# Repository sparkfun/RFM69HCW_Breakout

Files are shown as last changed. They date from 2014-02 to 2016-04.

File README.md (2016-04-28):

RFM69HCW Breakout Board
=================
The RFM69HCW is an inexpensive and versatile radio module that operates in the unlicensed ISM (Industry, Science, and Medicine) radio band. It's perfect for building inexpensive short-range wireless networks of sensors and actuators for home automation, citizen science, and more.

(https://cdn.sparkfun.com/assets/parts/9/6/6/5/12823-00.jpg)

Specs
----------------

* Transmit power: -18dBm (0.016mW) to +20dBm (100mW) in 1dBm steps
* Receive sensitivity: down to -120dBm at 1.2kbps
* Modulation types: FSK GFSK MSK GMSK OOK
* Bit rates (FSK): 1.2kbps to 300kbps
* Voltage range: 1.8V to 3.6V
* Current consumption: 0.1uA sleep, 1.25mA standby, 16mA receive, 
* 130mA transmit (max)
* Encryption: AES 128-bit (optional)
* Packet buffer (FIFO): 66 bytes
* Dimensions: 0.8" x 1.1"

Product Versions
----------------

The RFM69HCW modules transmit in the [ISM band](http://en.wikipedia.org/wiki/ISM_band), which is reserved for short-range, low-power communications. SparkFun sells the RFM69HCW Breakout Board in two frequencies:

* [**RFM69HCW Breakout 915MHz (WRL-12775)**](https://www.sparkfun.com/products/12775)
* [**RFM69HCW Breakout 433MHz (WRL-12823)**](https://www.sparkfun.com/products/12823)

Broadly speaking, the 915MHz version is legal in [ITU region](http://en.wikipedia.org/wiki/ITU_region) 2 (North and South America, Australia, Greenland, Pacific Islands, Israel), and the 433MHz version is legal in [ITU region](http://en.wikipedia.org/wiki/ITU_region) 1 (Europe, Africa, Middle East, Russia). Other areas have mixed allocations; hobbyist use is not likely to be an issue, but if you're going to be deploying a lot of these or using them in a commercial product, check your local regulations.

Documentation
-------------------

* [**Hookup Guide**](https://learn.sparkfun.com/tutorials/rfm69hcw-hookup-guide)
* [**RFM69HCW Breakout Board Schematic**](https://github.com/sparkfun/RFM69HCW_Breakout/blob/master/documentation/RFM69HCW_BOB.pdf)
* [**RFM69HCW datasheet**](https://github.com/sparkfun/RFM69HCW_Breakout/blob/master/documentation/RFM69HCW-V1.1.pdf)
* [**HopeRF RFM69HCW product page (external link)**](http://www.hoperf.com/rf/fsk_module/RFM69HCW.htm)

Repository Contents
-------------------
* [**/Libraries/Arduino**](https://github.com/sparkfun/RFM69HCW_Breakout/tree/master/Libraries/Arduino) - Contains the [RFM69 library](https://github.com/LowPowerLab/RFM69) written by Felix Rusu of [LowPowerLab.com](lowpowerlab.com). See [https://github.com/LowPowerLab/RFM69](https://github.com/LowPowerLab/RFM69) for the most up-to-date version.

* [**/Libraries/Arduino/RFM69/examples**](https://github.com/sparkfun/RFM69HCW_Breakout/tree/master/Libraries/Arduino/RFM69/examples) - Example Arduino sketch showing how to use the SparkFun RFM69HCW breakout board. See the hook-up guide at [https://learn.sparkfun.com/tutorials/rfm69hcw-hookup-guide](https://learn.sparkfun.com/tutorials/rfm69hcw-hookup-guide) for wiring and usage details.

* [**/hardware**](https://github.com/sparkfun/RFM69HCW_Breakout/tree/master/hardware) - Eagle design files (.brd, .sch)

* [**/documentation**](https://github.com/sparkfun/RFM69HCW_Breakout/tree/master/documentation) - Datasheets, schematic, etc.

Attribution
-----------
We gratefully acknowledge Felix Rusu of [LowPowerLab.com](lowpowerlab.com) for his terrific [RFM69 library](https://github.com/LowPowerLab/RFM69), which runs on his very cool [Moteino](http://lowpowerlab.com/moteino/) hardware. A version of his library is included here for the convenience of SparkFun customers. Please see his [GitHub repository](https://github.com/LowPowerLab/RFM69) for the latest version.

License Information
-------------------
The hardware design is released under the [Creative Commons Attribution-ShareAlike 4.0 International](http://creativecommons.org/licenses/by-sa/4.0/) license.

Felix Rusu's RFM69 library is released under the [Creative Commons Attribution-ShareAlike 3.0](http://creativecommons.org/licenses/by-sa/3.0/) license. 

SparkFun's example code is based on Felix Rusu's work, and is thus released under the same [Creative Commons Attribution-ShareAlike 3.0](http://creativecommons.org/licenses/by-sa/3.0/) license.

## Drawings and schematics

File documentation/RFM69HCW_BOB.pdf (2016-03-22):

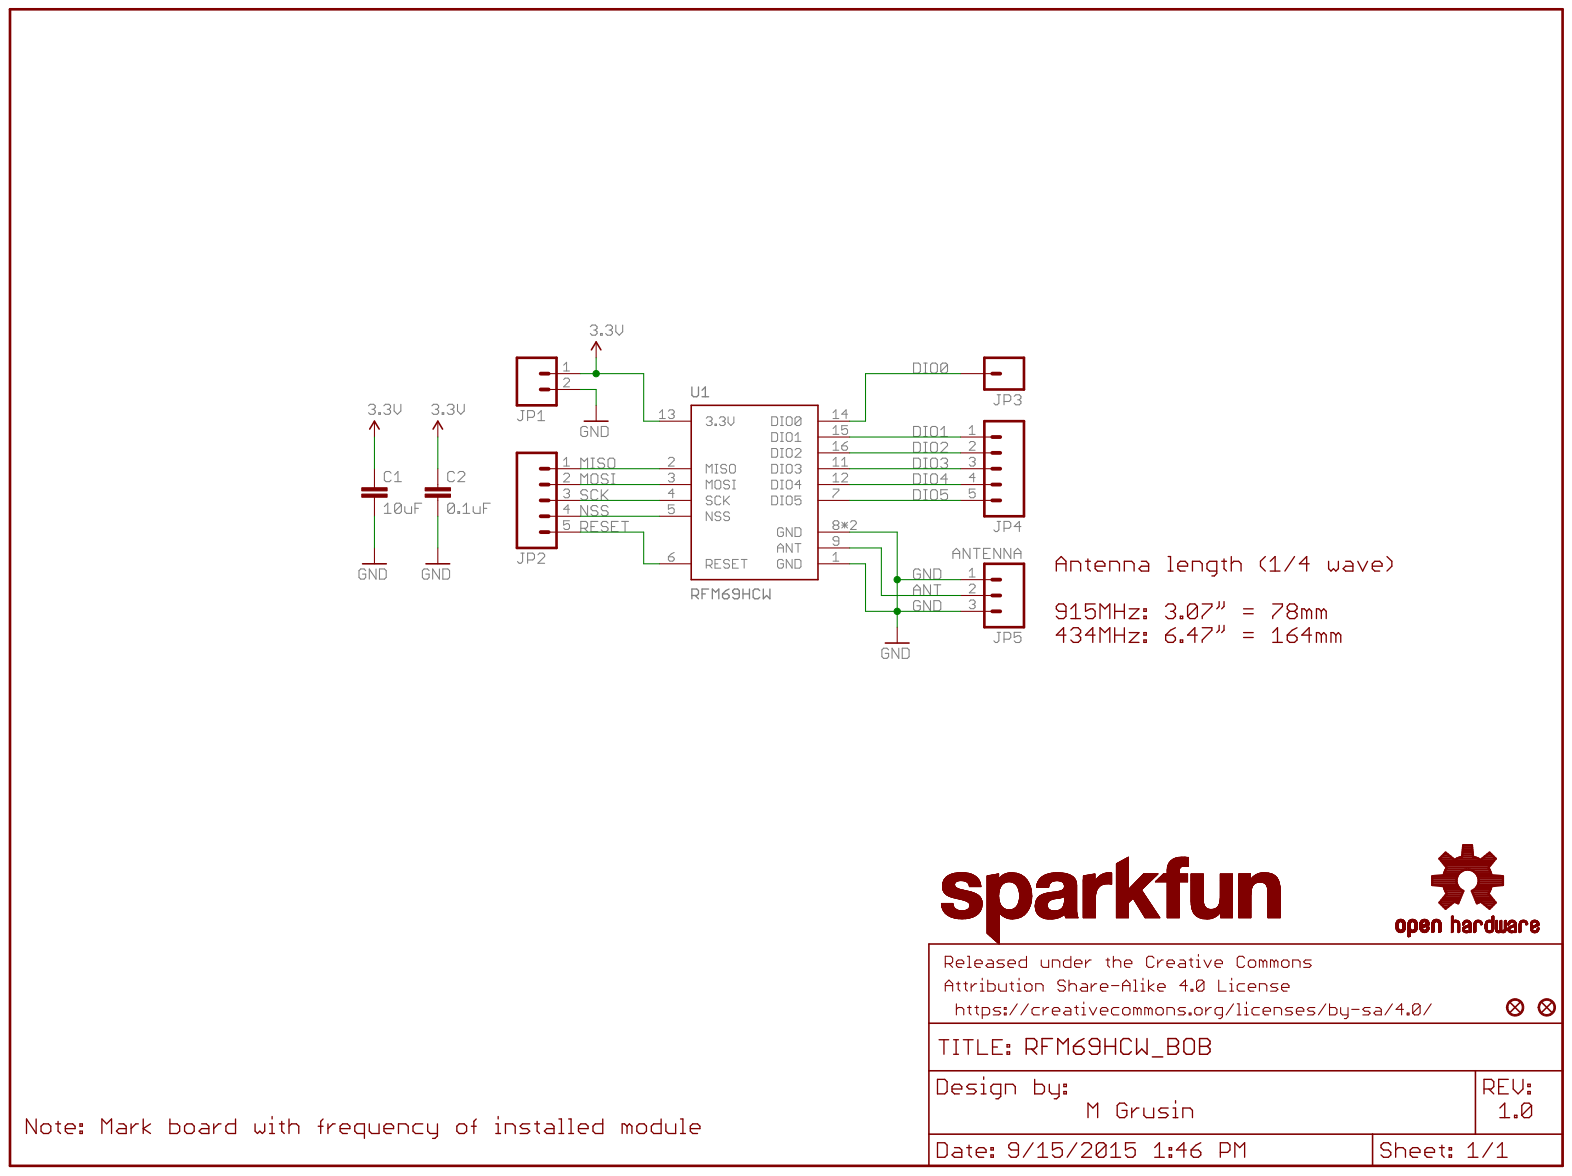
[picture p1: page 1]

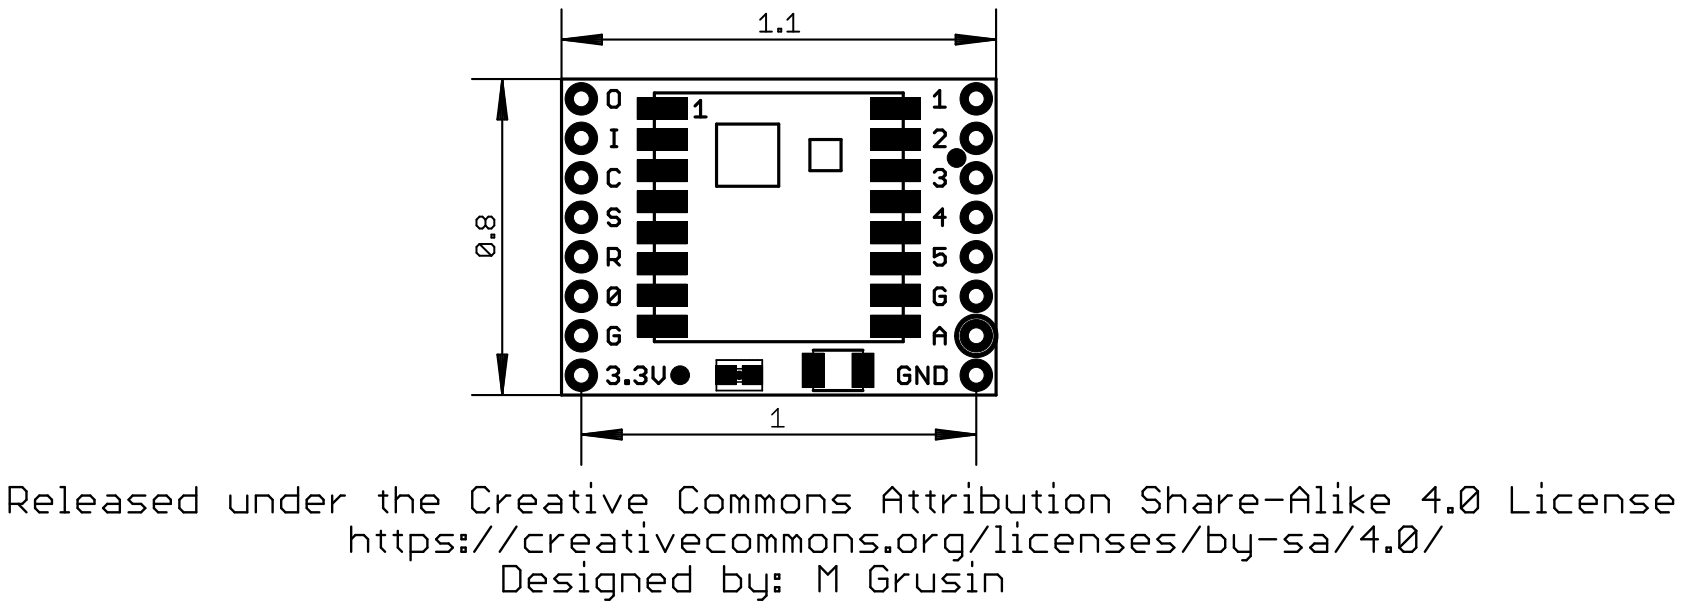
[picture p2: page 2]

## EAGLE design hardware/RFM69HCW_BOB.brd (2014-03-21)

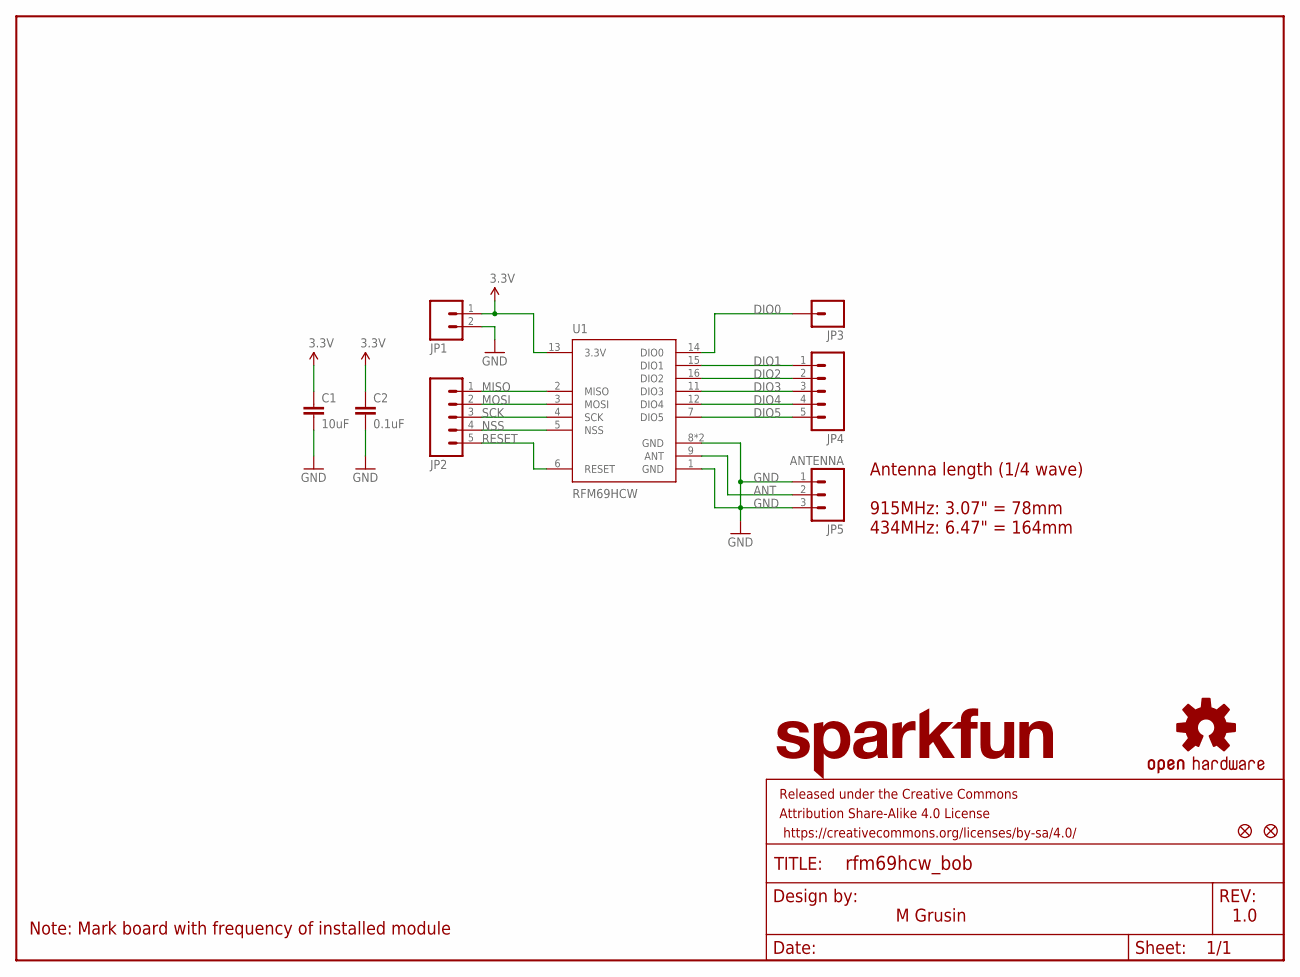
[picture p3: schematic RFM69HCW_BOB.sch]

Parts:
C1: 10uF; 1210
C2: 0.1uF; 0603-CAP
FID1, FID2: FIDUCIAL1X2; FIDUCIAL-1X2
FRAME1: FRAME-LETTER; CREATIVE_COMMONS
JP1: M021X02_NO_SILK; 1X02_NO_SILK
JP2, JP4: M05_ROUNDONLY_NOSILK; 1X05_ROUNDONLY_NOSILK
JP3: M01SMDNS; 1X01NS
JP5: ANTENNA; 1X03_ROUND_ONLY_NO_SILK
LOGO1: SFE_LOGO_NAME.1_INCH; SFE_LOGO_NAME_.1
LOGO2: OSHW-LOGOS; OSHW-LOGO-S
U1: RFM69HCW; RFM69HCW-XXXS2

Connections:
3.3V: C1.1, C2.1, JP1.1, U1.13 (3.3V)
ANT: JP5.2, U1.9 (ANT)
DIO0: JP3.1, U1.14 (DIO0)
DIO1: JP4.1, U1.15 (DIO1)
DIO2: JP4.2, U1.16 (DIO2)
DIO3: JP4.3, U1.11 (DIO3)
DIO4: JP4.4, U1.12 (DIO4)
DIO5: JP4.5, U1.7 (DIO5)
GND: C1.2, C2.2, JP1.2, JP5.1, JP5.3, U1.1 (GND), U1.8 (GND), U1.10 (GND)
MISO: JP2.1, U1.2 (MISO)
MOSI: JP2.2, U1.3 (MOSI)
NSS: JP2.4, U1.5 (NSS)
RESET: JP2.5, U1.6 (RESET)
SCK: JP2.3, U1.4 (SCK)

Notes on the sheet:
M Grusin
1.0
Note: Mark board with frequency of installed module
Antenna length (1/4 wave) 915MHz: 3.07" = 78mm 434MHz: 6.47" = 164mm

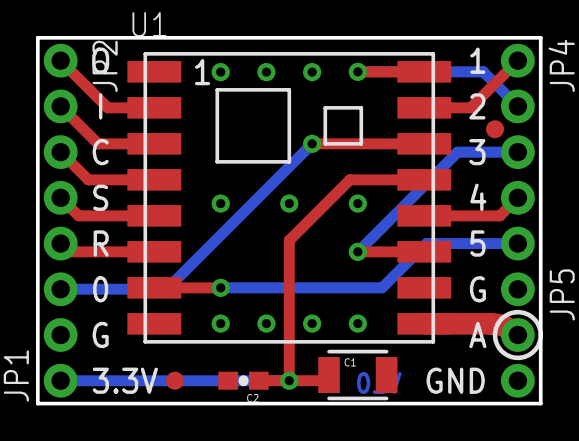
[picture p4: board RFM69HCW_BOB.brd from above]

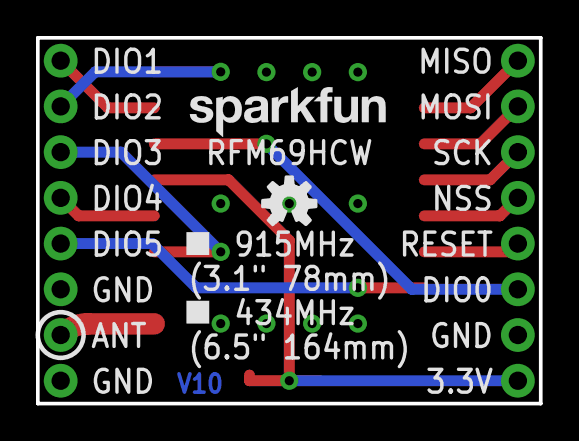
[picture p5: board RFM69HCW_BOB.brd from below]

Board: 2 copper layers, 27.9 x 20.3 mm, 13 parts (2 on the bottom side), 14 nets.

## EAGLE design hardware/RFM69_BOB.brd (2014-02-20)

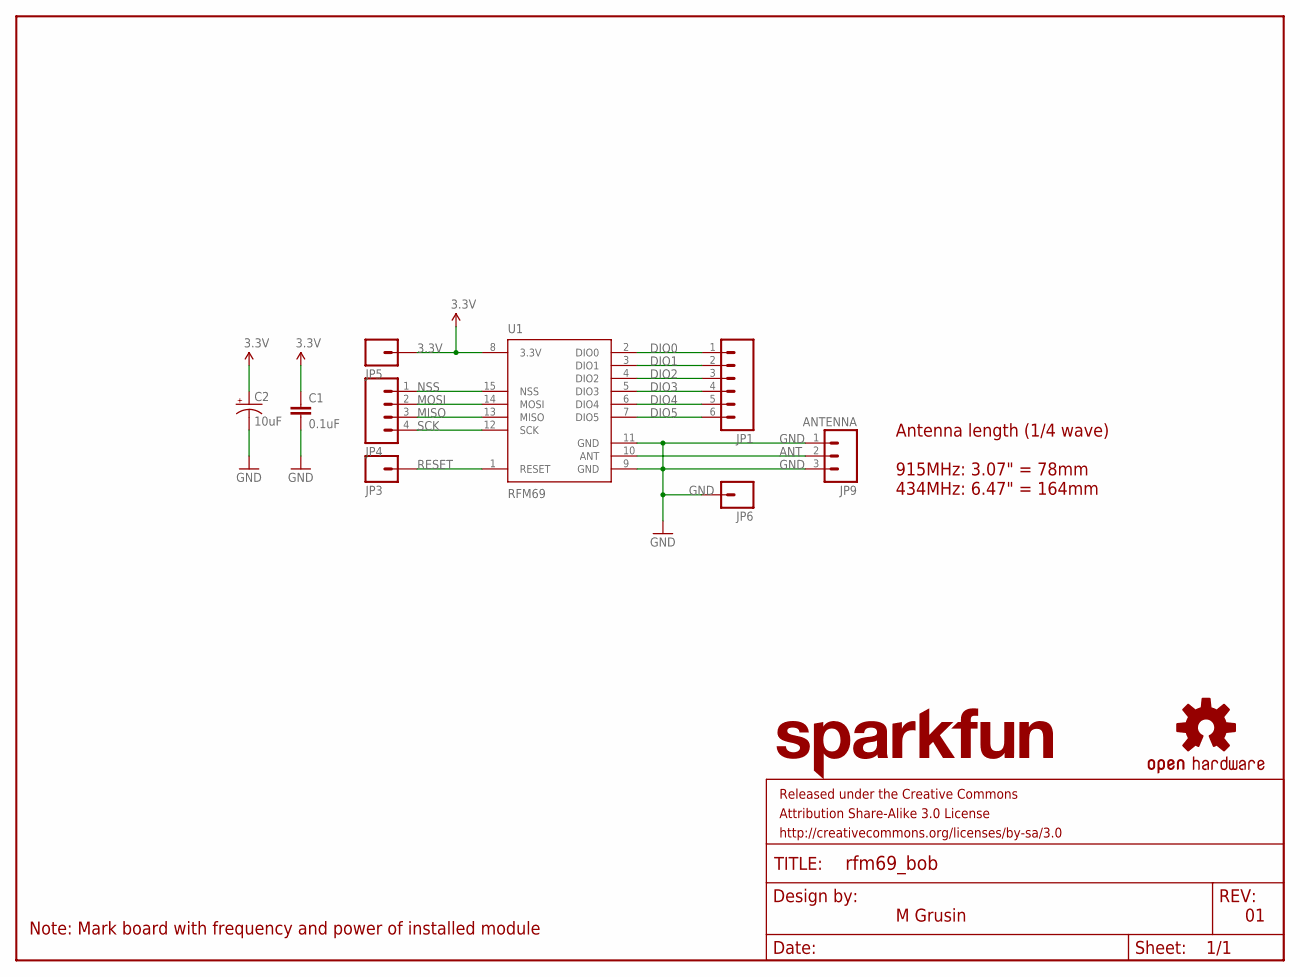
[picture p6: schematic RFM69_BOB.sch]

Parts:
C1: 0.1uF; 0603-CAP
C2: 10uF; EIA3216
FRAME1: FRAME-LETTER; CREATIVE_COMMONS
JP1: M06_NOSILK_ROUND; 1X06_NO_SILK_ROUND
JP3, JP5, JP6: M01SMDNS; 1X01NS
JP4: M041X04_NO_SILK_ROUND; 1X04_NO_SILK_ROUND
JP9: ANTENNA; 1X03_ROUND_ONLY_NO_SILK
LOGO1: SFE_LOGO_NAME.1_INCH; SFE_LOGO_NAME_.1
LOGO2: OSHW-LOGOS; OSHW-LOGO-S
U1: RFM69

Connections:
3.3V: C1.1, C2.A (+), JP5.1, U1.8 (3.3V)
ANT: JP9.2, U1.10 (ANT)
DIO0: JP1.1, U1.2 (DIO0)
DIO1: JP1.2, U1.3 (DIO1)
DIO2: JP1.3, U1.4 (DIO2)
DIO3: JP1.4, U1.5 (DIO3)
DIO4: JP1.5, U1.6 (DIO4)
DIO5: JP1.6, U1.7 (DIO5)
GND: C1.2, C2.C (-), JP6.1, JP9.1, JP9.3, U1.9 (GND), U1.11 (GND)
MISO: JP4.3, U1.13 (MISO)
MOSI: JP4.2, U1.14 (MOSI)
NSS: JP4.1, U1.15 (NSS)
RESET: JP3.1, U1.1 (RESET)
SCK: JP4.4, U1.12 (SCK)

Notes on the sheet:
M Grusin
Note: Mark board with frequency and power of installed module
Antenna length (1/4 wave) 915MHz: 3.07" = 78mm 434MHz: 6.47" = 164mm

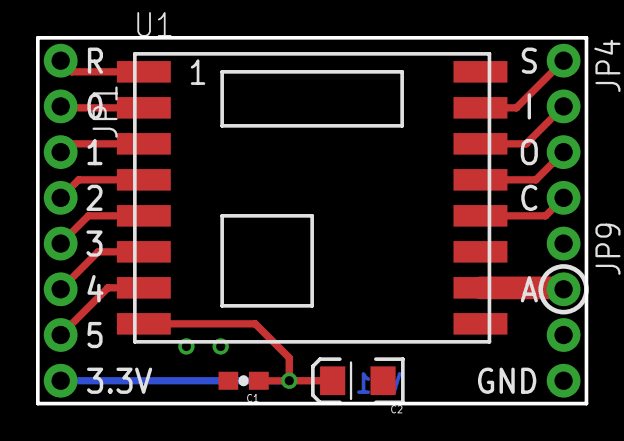
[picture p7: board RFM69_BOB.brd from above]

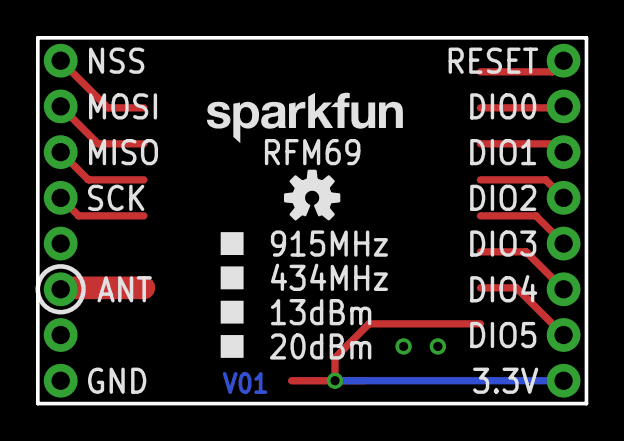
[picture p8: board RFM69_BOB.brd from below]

Board: 2 copper layers, 30.5 x 20.3 mm, 12 parts (2 on the bottom side), 14 nets.

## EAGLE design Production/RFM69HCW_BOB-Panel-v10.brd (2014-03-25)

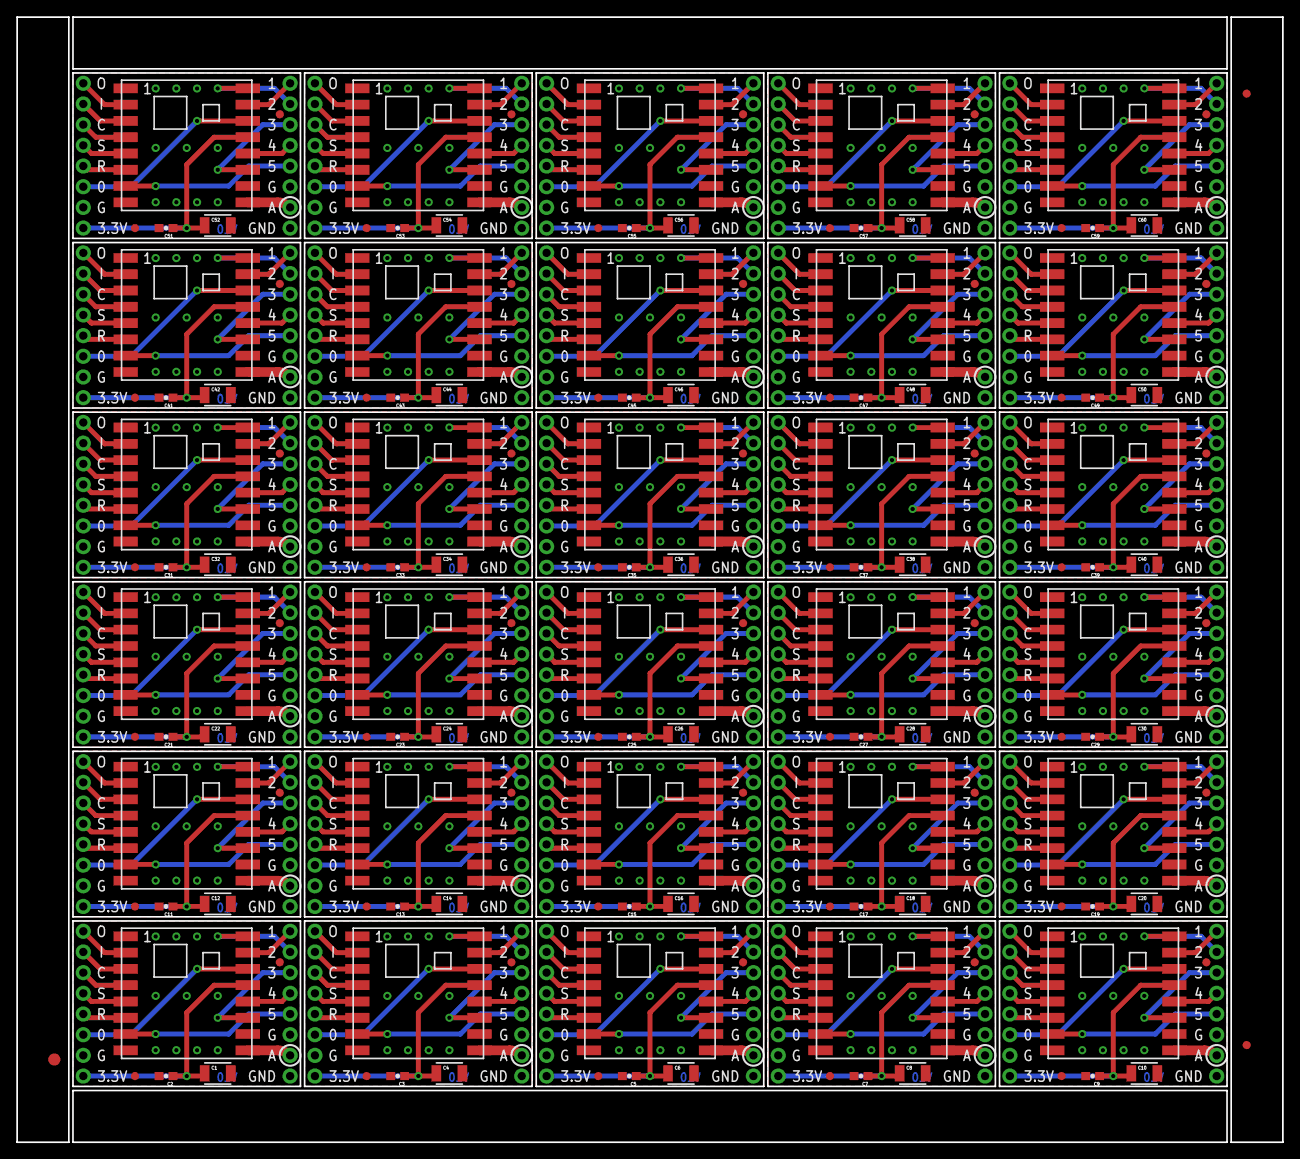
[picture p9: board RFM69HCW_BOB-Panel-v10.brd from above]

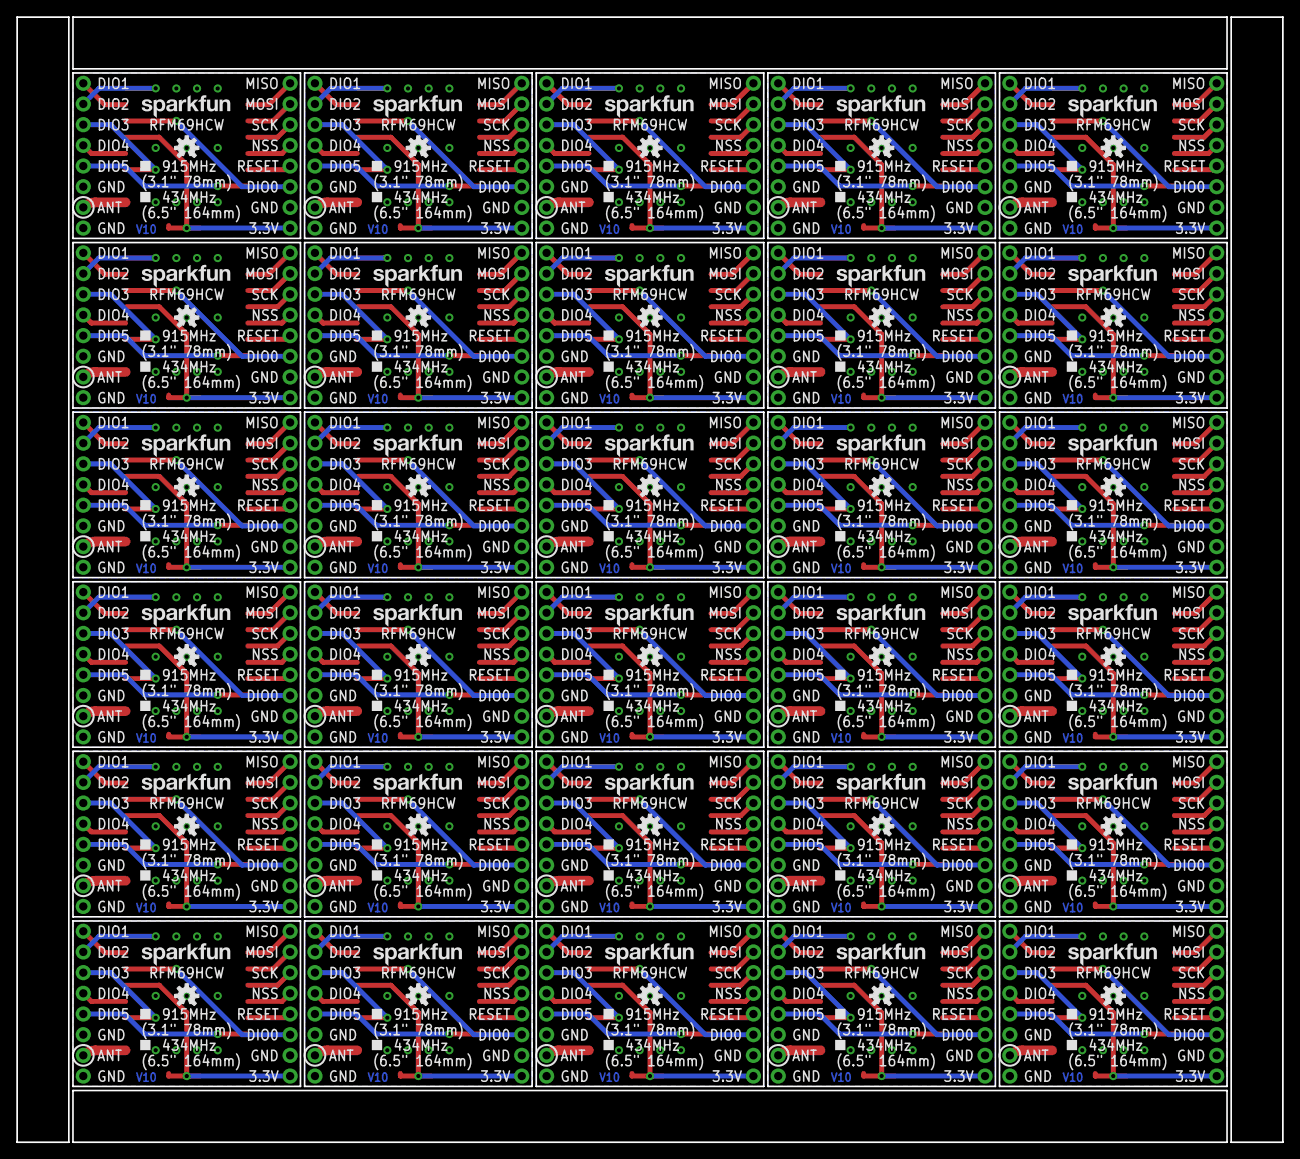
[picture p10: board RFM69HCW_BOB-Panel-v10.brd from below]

Board: 2 copper layers, 155.4 x 138.2 mm, 363 parts (60 on the bottom side), 420 nets.

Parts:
C1, C4, C6, C8, C10, C12, C14, C16, C18, C20, C22, C24, C26, C28, C30, C32, C34, C36, C38, C40, C42, C44, C46, C48, C50, C52, C54, C56, C58, C60: 10uF; 1210
C2, C3, C5, C7, C9, C11, C13, C15, C17, C19, C21, C23, C25, C27, C29, C31, C33, C35, C37, C39, C41, C43, C45, C47, C49, C51, C53, C55, C57, C59: 0.1uF; 0603-CAP
E$1: FIDUCIAL-1.5X3
E$4, E$6: FIDUCIAL-1X2
FID1, FID2, FID3, FID4, FID5, FID6, FID7, FID8, FID9, FID10, FID11, FID12, FID13, FID14, FID15, FID16, FID17, FID18, FID19, FID20, FID21, FID22, FID23, FID24, FID25, FID26, FID27, FID28, FID29, FID30, FID31, FID32, FID33, FID34, FID35, FID36, FID37, FID38, FID39, FID40, FID41, FID42, FID43, FID44, FID45, FID46, FID47, FID48, FID49, FID50, FID51, FID52, FID53, FID54, FID55, FID56, FID57, FID58, FID59, FID60: FIDUCIAL1X2; FIDUCIAL-1X2
JP1, JP7, JP12, JP17, JP22, JP27, JP32, JP37, JP42, JP47, JP52, JP57, JP62, JP67, JP72, JP77, JP82, JP87, JP92, JP97, JP102, JP107, JP112, JP117, JP122, JP127, JP132, JP137, JP142, JP147: 1X02_NO_SILK
JP2, JP4, JP8, JP10, JP13, JP15, JP18, JP20, JP23, JP25, JP28, JP30, JP33, JP35, JP38, JP40, JP43, JP45, JP48, JP50, JP53, JP55, JP58, JP60, JP63, JP65, JP68, JP70, JP73, JP75, JP78, JP80, JP83, JP85, JP88, JP90, JP93, JP95, JP98, JP100, JP103, JP105, JP108, JP110, JP113, JP115, JP118, JP120, JP123, JP125, JP128, JP130, JP133, JP135, JP138, JP140, JP143, JP145, JP148, JP150: 1X05_ROUNDONLY_NOSILK
JP3, JP9, JP14, JP19, JP24, JP29, JP34, JP39, JP44, JP49, JP54, JP59, JP64, JP69, JP74, JP79, JP84, JP89, JP94, JP99, JP104, JP109, JP114, JP119, JP124, JP129, JP134, JP139, JP144, JP149: 1X01NS
JP5, JP6, JP11, JP16, JP21, JP26, JP31, JP36, JP41, JP46, JP51, JP56, JP61, JP66, JP71, JP76, JP81, JP86, JP91, JP96, JP101, JP106, JP111, JP116, JP121, JP126, JP131, JP136, JP141, JP146: ANTENNA; 1X03_ROUND_ONLY_NO_SILK
LOGO1, LOGO3, LOGO5, LOGO7, LOGO9, LOGO11, LOGO13, LOGO15, LOGO17, LOGO19, LOGO21, LOGO23, LOGO25, LOGO27, LOGO29, LOGO31, LOGO33, LOGO35, LOGO37, LOGO39, LOGO41, LOGO43, LOGO45, LOGO47, LOGO49, LOGO51, LOGO53, LOGO55, LOGO57, LOGO59: SFE_LOGO_NAME.1_INCH; SFE_LOGO_NAME_.1
LOGO2, LOGO4, LOGO6, LOGO8, LOGO10, LOGO12, LOGO14, LOGO16, LOGO18, LOGO20, LOGO22, LOGO24, LOGO26, LOGO28, LOGO30, LOGO32, LOGO34, LOGO36, LOGO38, LOGO40, LOGO42, LOGO44, LOGO46, LOGO48, LOGO50, LOGO52, LOGO54, LOGO56, LOGO58, LOGO60: OSHW-LOGOS; OSHW-LOGO-S
U1, U2, U3, U4, U5, U6, U7, U8, U9, U10, U11, U12, U13, U14, U15, U16, U17, U18, U19, U20, U21, U22, U23, U24, U25, U26, U27, U28, U29, U30: RFM69HCW; RFM69HCW-XXXS2

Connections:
3.3V: C1.1, C2.1, JP1.1, U1.13
3.3V1: C3.1, C4.1, JP7.1, U2.13
3.3V2: C5.1, C6.1, JP12.1, U3.13
3.3V3: C7.1, C8.1, JP17.1, U4.13
3.3V4: C9.1, C10.1, JP22.1, U5.13
3.3V5: C11.1, C12.1, JP27.1, U6.13
3.3V6: C13.1, C14.1, JP32.1, U7.13
3.3V7: C15.1, C16.1, JP37.1, U8.13
3.3V8: C17.1, C18.1, JP42.1, U9.13
3.3V9: C19.1, C20.1, JP47.1, U10.13
3.3V10: C21.1, C22.1, JP52.1, U11.13
3.3V11: C23.1, C24.1, JP57.1, U12.13
3.3V12: C25.1, C26.1, JP62.1, U13.13
3.3V13: C27.1, C28.1, JP67.1, U14.13
3.3V14: C29.1, C30.1, JP72.1, U15.13
3.3V15: C31.1, C32.1, JP77.1, U16.13
3.3V16: C33.1, C34.1, JP82.1, U17.13
3.3V17: C35.1, C36.1, JP87.1, U18.13
3.3V18: C37.1, C38.1, JP92.1, U19.13
3.3V19: C39.1, C40.1, JP97.1, U20.13
3.3V20: C41.1, C42.1, JP102.1, U21.13
3.3V21: C43.1, C44.1, JP107.1, U22.13
3.3V22: C45.1, C46.1, JP112.1, U23.13
3.3V23: C47.1, C48.1, JP117.1, U24.13
3.3V24: C49.1, C50.1, JP122.1, U25.13
3.3V25: C51.1, C52.1, JP127.1, U26.13
3.3V26: C53.1, C54.1, JP132.1, U27.13
3.3V27: C55.1, C56.1, JP137.1, U28.13
3.3V28: C57.1, C58.1, JP142.1, U29.13
3.3V29: C59.1, C60.1, JP147.1, U30.13
ANT: JP5.2, U1.9
ANT1: JP6.2, U2.9
ANT2: JP11.2, U3.9
ANT3: JP16.2, U4.9
ANT4: JP21.2, U5.9
ANT5: JP26.2, U6.9
ANT6: JP31.2, U7.9
ANT7: JP36.2, U8.9
ANT8: JP41.2, U9.9
ANT9: JP46.2, U10.9
ANT10: JP51.2, U11.9
ANT11: JP56.2, U12.9
ANT12: JP61.2, U13.9
ANT13: JP66.2, U14.9
ANT14: JP71.2, U15.9
ANT15: JP76.2, U16.9
ANT16: JP81.2, U17.9
ANT17: JP86.2, U18.9
ANT18: JP91.2, U19.9
ANT19: JP96.2, U20.9
ANT20: JP101.2, U21.9
ANT21: JP106.2, U22.9
ANT22: JP111.2, U23.9
ANT23: JP116.2, U24.9
ANT24: JP121.2, U25.9
ANT25: JP126.2, U26.9
ANT26: JP131.2, U27.9
ANT27: JP136.2, U28.9
ANT28: JP141.2, U29.9
ANT29: JP146.2, U30.9
DIO0: JP3.1, U1.14
DIO1: JP4.1, U1.15
DIO2: JP4.2, U1.16
DIO3: JP4.3, U1.11
DIO4: JP4.4, U1.12
DIO5: JP4.5, U1.7
DIO6: JP9.1, U2.14
DIO7: JP10.1, U2.15
DIO8: JP10.2, U2.16
DIO9: JP10.3, U2.11
DIO10: JP10.5, U2.7
DIO11: JP10.4, U2.12
DIO12: JP14.1, U3.14
DIO13: JP15.1, U3.15
DIO14: JP15.2, U3.16
DIO15: JP15.3, U3.11
DIO16: JP15.5, U3.7
DIO17: JP15.4, U3.12
DIO18: JP19.1, U4.14
DIO19: JP20.1, U4.15
DIO20: JP20.2, U4.16
DIO21: JP20.3, U4.11
DIO22: JP20.5, U4.7
DIO23: JP20.4, U4.12
DIO24: JP24.1, U5.14
DIO25: JP25.1, U5.15
DIO26: JP25.2, U5.16
DIO27: JP25.3, U5.11
DIO28: JP25.5, U5.7
DIO29: JP25.4, U5.12
DIO30: JP29.1, U6.14
DIO31: JP30.1, U6.15
DIO32: JP30.2, U6.16
DIO33: JP30.3, U6.11
DIO34: JP30.5, U6.7
DIO35: JP30.4, U6.12
DIO36: JP34.1, U7.14
DIO37: JP35.1, U7.15
DIO38: JP35.2, U7.16
DIO39: JP35.3, U7.11
DIO40: JP35.5, U7.7
DIO41: JP35.4, U7.12
DIO42: JP39.1, U8.14
DIO43: JP40.1, U8.15
DIO44: JP40.2, U8.16
DIO45: JP40.3, U8.11
DIO46: JP40.5, U8.7
DIO47: JP40.4, U8.12
DIO48: JP44.1, U9.14
DIO49: JP45.1, U9.15
DIO50: JP45.2, U9.16
DIO51: JP45.3, U9.11
DIO52: JP45.5, U9.7
DIO53: JP45.4, U9.12
DIO54: JP49.1, U10.14
DIO55: JP50.1, U10.15
DIO56: JP50.2, U10.16
DIO57: JP50.3, U10.11
DIO58: JP50.5, U10.7
DIO59: JP50.4, U10.12
DIO60: JP54.1, U11.14
DIO61: JP55.1, U11.15
DIO62: JP55.2, U11.16
DIO63: JP55.3, U11.11
DIO64: JP55.5, U11.7
DIO65: JP55.4, U11.12
DIO66: JP59.1, U12.14
DIO67: JP60.1, U12.15
DIO68: JP60.2, U12.16
DIO69: JP60.3, U12.11
DIO70: JP60.5, U12.7
DIO71: JP60.4, U12.12
DIO72: JP64.1, U13.14
DIO73: JP65.1, U13.15
DIO74: JP65.2, U13.16
DIO75: JP65.3, U13.11
DIO76: JP65.5, U13.7
DIO77: JP65.4, U13.12
DIO78: JP69.1, U14.14
DIO79: JP70.1, U14.15
DIO80: JP70.2, U14.16
DIO81: JP70.3, U14.11
DIO82: JP70.5, U14.7
DIO83: JP70.4, U14.12
DIO84: JP74.1, U15.14
DIO85: JP75.1, U15.15
DIO86: JP75.2, U15.16
DIO87: JP75.3, U15.11
DIO88: JP75.5, U15.7
DIO89: JP75.4, U15.12
DIO90: JP79.1, U16.14
DIO91: JP80.1, U16.15
DIO92: JP80.2, U16.16
DIO93: JP80.3, U16.11
DIO94: JP80.5, U16.7
DIO95: JP80.4, U16.12
DIO96: JP84.1, U17.14
DIO97: JP85.1, U17.15
DIO98: JP85.2, U17.16
DIO99: JP85.3, U17.11
DIO100: JP85.5, U17.7
DIO101: JP85.4, U17.12
DIO102: JP89.1, U18.14
DIO103: JP90.1, U18.15
DIO104: JP90.2, U18.16
DIO105: JP90.3, U18.11
DIO106: JP90.5, U18.7
DIO107: JP90.4, U18.12
DIO108: JP94.1, U19.14
DIO109: JP95.1, U19.15
DIO110: JP95.2, U19.16
DIO111: JP95.3, U19.11
DIO112: JP95.5, U19.7
DIO113: JP95.4, U19.12
DIO114: JP99.1, U20.14
DIO115: JP100.1, U20.15
DIO116: JP100.2, U20.16
DIO117: JP100.3, U20.11
DIO118: JP100.5, U20.7
DIO119: JP100.4, U20.12
DIO120: JP104.1, U21.14
DIO121: JP105.1, U21.15
DIO122: JP105.2, U21.16
DIO123: JP105.3, U21.11
DIO124: JP105.5, U21.7
DIO125: JP105.4, U21.12
DIO126: JP109.1, U22.14
DIO127: JP110.1, U22.15
DIO128: JP110.2, U22.16
DIO129: JP110.3, U22.11
DIO130: JP110.5, U22.7
DIO131: JP110.4, U22.12
DIO132: JP114.1, U23.14
DIO133: JP115.1, U23.15
DIO134: JP115.2, U23.16
DIO135: JP115.3, U23.11
DIO136: JP115.5, U23.7
DIO137: JP115.4, U23.12
DIO138: JP119.1, U24.14
DIO139: JP120.1, U24.15
DIO140: JP120.2, U24.16
DIO141: JP120.3, U24.11
DIO142: JP120.5, U24.7
DIO143: JP120.4, U24.12
DIO144: JP124.1, U25.14
DIO145: JP125.1, U25.15
DIO146: JP125.2, U25.16
DIO147: JP125.3, U25.11
DIO148: JP125.5, U25.7
DIO149: JP125.4, U25.12
DIO150: JP129.1, U26.14
DIO151: JP130.1, U26.15
DIO152: JP130.2, U26.16
DIO153: JP130.3, U26.11
DIO154: JP130.5, U26.7
DIO155: JP130.4, U26.12
DIO156: JP134.1, U27.14
DIO157: JP135.1, U27.15
DIO158: JP135.2, U27.16
DIO159: JP135.3, U27.11
DIO160: JP135.5, U27.7
DIO161: JP135.4, U27.12
DIO162: JP139.1, U28.14
DIO163: JP140.1, U28.15
DIO164: JP140.2, U28.16
DIO165: JP140.3, U28.11
DIO166: JP140.5, U28.7
DIO167: JP140.4, U28.12
DIO168: JP144.1, U29.14
DIO169: JP145.1, U29.15
DIO170: JP145.2, U29.16
DIO171: JP145.3, U29.11
DIO172: JP145.5, U29.7
DIO173: JP145.4, U29.12
DIO174: JP149.1, U30.14
DIO175: JP150.1, U30.15
DIO176: JP150.2, U30.16
DIO177: JP150.3, U30.11
DIO178: JP150.5, U30.7
DIO179: JP150.4, U30.12
GND: C1.2, C2.2, JP1.2, JP5.1, JP5.3, U1.1, U1.8, U1.10
GND1: C3.2, C4.2, JP6.1, JP6.3, JP7.2, U2.1, U2.8, U2.10
GND2: C5.2, C6.2, JP11.1, JP11.3, JP12.2, U3.1, U3.8, U3.10
GND3: C7.2, C8.2, JP16.1, JP16.3, JP17.2, U4.1, U4.8, U4.10
GND4: C9.2, C10.2, JP21.1, JP21.3, JP22.2, U5.1, U5.8, U5.10
GND5: C11.2, C12.2, JP26.1, JP26.3, JP27.2, U6.1, U6.8, U6.10
GND6: C13.2, C14.2, JP31.1, JP31.3, JP32.2, U7.1, U7.8, U7.10
GND7: C15.2, C16.2, JP36.1, JP36.3, JP37.2, U8.1, U8.8, U8.10
GND8: C17.2, C18.2, JP41.1, JP41.3, JP42.2, U9.1, U9.8, U9.10
GND9: C19.2, C20.2, JP46.1, JP46.3, JP47.2, U10.1, U10.8, U10.10
GND10: C21.2, C22.2, JP51.1, JP51.3, JP52.2, U11.1, U11.8, U11.10
GND11: C23.2, C24.2, JP56.1, JP56.3, JP57.2, U12.1, U12.8, U12.10
GND12: C25.2, C26.2, JP61.1, JP61.3, JP62.2, U13.1, U13.8, U13.10
GND13: C27.2, C28.2, JP66.1, JP66.3, JP67.2, U14.1, U14.8, U14.10
GND14: C29.2, C30.2, JP71.1, JP71.3, JP72.2, U15.1, U15.8, U15.10
GND15: C31.2, C32.2, JP76.1, JP76.3, JP77.2, U16.1, U16.8, U16.10
GND16: C33.2, C34.2, JP81.1, JP81.3, JP82.2, U17.1, U17.8, U17.10
GND17: C35.2, C36.2, JP86.1, JP86.3, JP87.2, U18.1, U18.8, U18.10
GND18: C37.2, C38.2, JP91.1, JP91.3, JP92.2, U19.1, U19.8, U19.10
GND19: C39.2, C40.2, JP96.1, JP96.3, JP97.2, U20.1, U20.8, U20.10
GND20: C41.2, C42.2, JP101.1, JP101.3, JP102.2, U21.1, U21.8, U21.10
GND21: C43.2, C44.2, JP106.1, JP106.3, JP107.2, U22.1, U22.8, U22.10
GND22: C45.2, C46.2, JP111.1, JP111.3, JP112.2, U23.1, U23.8, U23.10
GND23: C47.2, C48.2, JP116.1, JP116.3, JP117.2, U24.1, U24.8, U24.10
GND24: C49.2, C50.2, JP121.1, JP121.3, JP122.2, U25.1, U25.8, U25.10
GND25: C51.2, C52.2, JP126.1, JP126.3, JP127.2, U26.1, U26.8, U26.10
GND26: C53.2, C54.2, JP131.1, JP131.3, JP132.2, U27.1, U27.8, U27.10
GND27: C55.2, C56.2, JP136.1, JP136.3, JP137.2, U28.1, U28.8, U28.10
GND28: C57.2, C58.2, JP141.1, JP141.3, JP142.2, U29.1, U29.8, U29.10
GND29: C59.2, C60.2, JP146.1, JP146.3, JP147.2, U30.1, U30.8, U30.10
MISO: JP2.1, U1.2
MISO1: JP8.1, U2.2
MISO2: JP13.1, U3.2
MISO3: JP18.1, U4.2
MISO4: JP23.1, U5.2
MISO5: JP28.1, U6.2
MISO6: JP33.1, U7.2
MISO7: JP38.1, U8.2
MISO8: JP43.1, U9.2
MISO9: JP48.1, U10.2
MISO10: JP53.1, U11.2
MISO11: JP58.1, U12.2
MISO12: JP63.1, U13.2
MISO13: JP68.1, U14.2
MISO14: JP73.1, U15.2
MISO15: JP78.1, U16.2
MISO16: JP83.1, U17.2
MISO17: JP88.1, U18.2
MISO18: JP93.1, U19.2
MISO19: JP98.1, U20.2
MISO20: JP103.1, U21.2
MISO21: JP108.1, U22.2
MISO22: JP113.1, U23.2
MISO23: JP118.1, U24.2
MISO24: JP123.1, U25.2
MISO25: JP128.1, U26.2
MISO26: JP133.1, U27.2
MISO27: JP138.1, U28.2
MISO28: JP143.1, U29.2
MISO29: JP148.1, U30.2
MOSI: JP2.2, U1.3
MOSI1: JP8.2, U2.3
MOSI2: JP13.2, U3.3
MOSI3: JP18.2, U4.3
MOSI4: JP23.2, U5.3
MOSI5: JP28.2, U6.3
MOSI6: JP33.2, U7.3
MOSI7: JP38.2, U8.3
MOSI8: JP43.2, U9.3
MOSI9: JP48.2, U10.3
MOSI10: JP53.2, U11.3
MOSI11: JP58.2, U12.3
MOSI12: JP63.2, U13.3
MOSI13: JP68.2, U14.3
MOSI14: JP73.2, U15.3
MOSI15: JP78.2, U16.3
MOSI16: JP83.2, U17.3
MOSI17: JP88.2, U18.3
MOSI18: JP93.2, U19.3
MOSI19: JP98.2, U20.3
MOSI20: JP103.2, U21.3
MOSI21: JP108.2, U22.3
MOSI22: JP113.2, U23.3
MOSI23: JP118.2, U24.3
MOSI24: JP123.2, U25.3
MOSI25: JP128.2, U26.3
MOSI26: JP133.2, U27.3
MOSI27: JP138.2, U28.3
MOSI28: JP143.2, U29.3
MOSI29: JP148.2, U30.3
NSS: JP2.4, U1.5
NSS1: JP8.4, U2.5
NSS2: JP13.4, U3.5
NSS3: JP18.4, U4.5
NSS4: JP23.4, U5.5
NSS5: JP28.4, U6.5
NSS6: JP33.4, U7.5
NSS7: JP38.4, U8.5
NSS8: JP43.4, U9.5
NSS9: JP48.4, U10.5
NSS10: JP53.4, U11.5
NSS11: JP58.4, U12.5
NSS12: JP63.4, U13.5
NSS13: JP68.4, U14.5
NSS14: JP73.4, U15.5
NSS15: JP78.4, U16.5
NSS16: JP83.4, U17.5
NSS17: JP88.4, U18.5
NSS18: JP93.4, U19.5
NSS19: JP98.4, U20.5
NSS20: JP103.4, U21.5
NSS21: JP108.4, U22.5
NSS22: JP113.4, U23.5
NSS23: JP118.4, U24.5
NSS24: JP123.4, U25.5
NSS25: JP128.4, U26.5
NSS26: JP133.4, U27.5
NSS27: JP138.4, U28.5
NSS28: JP143.4, U29.5
NSS29: JP148.4, U30.5
RESET: JP2.5, U1.6
RESET1: JP8.5, U2.6
RESET2: JP13.5, U3.6
RESET3: JP18.5, U4.6
RESET4: JP23.5, U5.6
RESET5: JP28.5, U6.6
RESET6: JP33.5, U7.6
RESET7: JP38.5, U8.6
RESET8: JP43.5, U9.6
RESET9: JP48.5, U10.6
RESET10: JP53.5, U11.6
RESET11: JP58.5, U12.6
RESET12: JP63.5, U13.6
RESET13: JP68.5, U14.6
RESET14: JP73.5, U15.6
RESET15: JP78.5, U16.6
RESET16: JP83.5, U17.6
RESET17: JP88.5, U18.6
RESET18: JP93.5, U19.6
RESET19: JP98.5, U20.6
RESET20: JP103.5, U21.6
RESET21: JP108.5, U22.6
RESET22: JP113.5, U23.6
RESET23: JP118.5, U24.6
RESET24: JP123.5, U25.6
RESET25: JP128.5, U26.6
RESET26: JP133.5, U27.6
RESET27: JP138.5, U28.6
RESET28: JP143.5, U29.6
RESET29: JP148.5, U30.6
SCK: JP2.3, U1.4
SCK1: JP8.3, U2.4
SCK2: JP13.3, U3.4
SCK3: JP18.3, U4.4
SCK4: JP23.3, U5.4
SCK5: JP28.3, U6.4
SCK6: JP33.3, U7.4
SCK7: JP38.3, U8.4
SCK8: JP43.3, U9.4
SCK9: JP48.3, U10.4
SCK10: JP53.3, U11.4
SCK11: JP58.3, U12.4
SCK12: JP63.3, U13.4
SCK13: JP68.3, U14.4
SCK14: JP73.3, U15.4
SCK15: JP78.3, U16.4
SCK16: JP83.3, U17.4
SCK17: JP88.3, U18.4
SCK18: JP93.3, U19.4
SCK19: JP98.3, U20.4
SCK20: JP103.3, U21.4
SCK21: JP108.3, U22.4
SCK22: JP113.3, U23.4
SCK23: JP118.3, U24.4
SCK24: JP123.3, U25.4
SCK25: JP128.3, U26.4
SCK26: JP133.3, U27.4
SCK27: JP138.3, U28.4
SCK28: JP143.3, U29.4
SCK29: JP148.3, U30.4

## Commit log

2014-02-20 Changed part to 'C' (compact) variant
    New footprint, changed name to ensure proper variant is used (RFM69CW or
    RFM69HCW)
    [RFM69C_BOB.brd, RFM69C_BOB.sch]
2014-02-21 Renamed board to HCW
    C (low power) and HC (high power) parts have different footprints;
    renamed board and part for HC footprint.
    [RFM69HCW_BOB.brd, RFM69HCW_BOB.sch]
2014-02-21 Minor silk updates
    [RFM69HCW_BOB.brd, RFM69HCW_BOB.sch]
2014-02-21 Deleted incorrect "C" variant
    [RFM69C_BOB.brd, RFM69C_BOB.sch]
2014-03-17 HCW BOB to 1.0, CW BOB to 0.1
    [RFM69CW_BOB.brd, RFM69CW_BOB.sch]
2014-03-18 Added fiducials to HCW BOB, initial example code
    [RFM69HCW_BOB.brd, RFM69HCW_BOB.sch]
2014-03-18 Changed capacitor, removed C variant
    Changed C1 to CAP-9824 (10uF ceramic for better transient response)
    Removed RFM69C (low power) for future BOB
    [RFM69CW_BOB.brd, RFM69CW_BOB.sch, RFM69HCW_BOB.brd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]
2014-03-18 Changed version to 1.0 for reds
    [RFM69HCW_BOB.brd, RFM69HCW_BOB.sch]
2014-03-21 Minor silk and routing tweaks for reds
    [RFM69HCW_BOB.brd, RFM69HCW_BOB.sch]
2014-03-21 cleanup for reds
    [RFM69HCW_BOB.brd]
2014-03-25 created panel v10
    [RFM69HCW_BOB-Panel-v10.brd]
2014-04-03 More example code: simple_chat_with_ACK
    Simple_chat_with_ACK: set up #defines with node numbers, upload, send
    text to board, CR sends message. Turn on "promiscuous mode" to see all
    messages. Uses ACK to verify reception (or not).
2016-03-22 Added schematic PDF, code update
2016-03-22 Moved schematic PDF to docs
2016-04-28 broad changes for product release
    [RFM69HCW_BOB-Panel-v10.brd]

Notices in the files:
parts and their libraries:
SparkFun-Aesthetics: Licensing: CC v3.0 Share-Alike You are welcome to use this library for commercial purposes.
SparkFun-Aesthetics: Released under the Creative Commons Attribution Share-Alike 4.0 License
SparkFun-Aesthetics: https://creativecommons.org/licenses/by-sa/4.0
